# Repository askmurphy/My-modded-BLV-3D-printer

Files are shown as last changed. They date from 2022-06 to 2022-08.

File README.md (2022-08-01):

# My modded BLV 3D-printer

For starters I build the original BLV printer following the original design.
It worked but because I build the largest version, it didn't print very good..
So, time to do some modifications, a lot of them....  Finally I am now at my BLV printer version 3 ;-)

# <strong>My current setup:</strong> 

# HARDWARE:
* BLV Alu profiles
* Original Duet2Wifi board
* Clone Duex5 board
* Big heated bed
* Orbiter 1.5 extruder
* NF Crazy hotend
* Triple Z-as (SFU1204, MGN rails)
* Accelerator
* 24V Meanwell PSU

| Just a few photo's | Click to enlarge..|
|---|---|

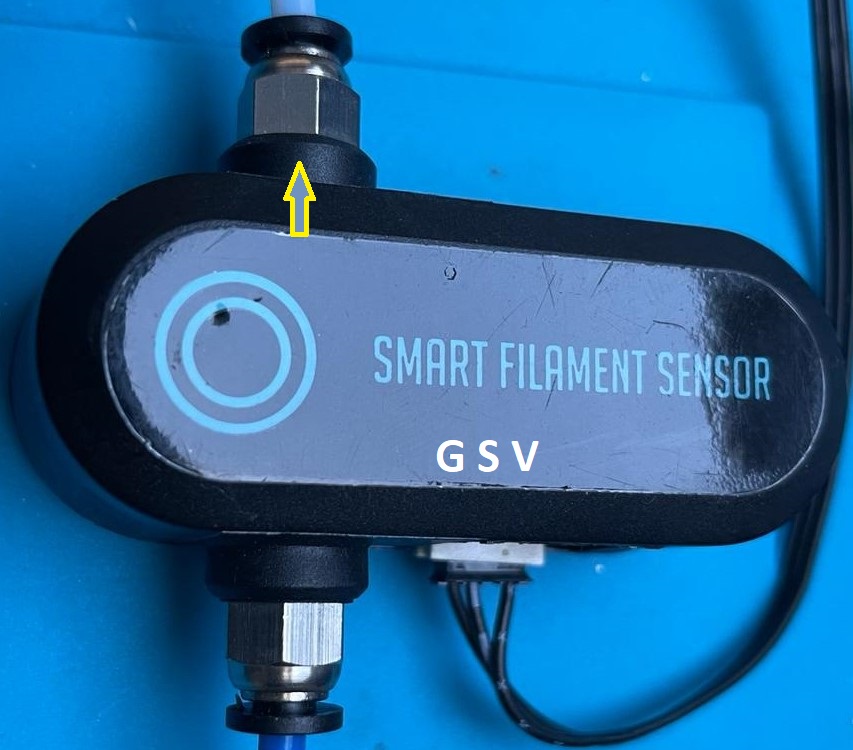
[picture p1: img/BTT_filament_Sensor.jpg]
BTT smart filament sensor Bigtreetech filament sensor
|  

# FIRMWARE:
* RepRapFirmware for Duet 2 WiFi/Ethernet 3.4.0 (2022-03-15)
* Duet WiFi Server Version: 1.26
* Duet Web Control 3.4.0

# Accelerator LIS3DSH
Because this device needs a very good shielded cable to avoid malfunctions, I have used an UTP CAT7 cable. The accelerator can be connected to the 10 pins header named 'TEMP DAUGHTERBOARD', located on the DUET2WIFI and DUEX5, wiring:

| UTP | Accelerator | DUET2WIFI | DUEX5 |
|---|---|---|---|
| UTP[1] white/orange | INT1 | SPI_CS3[7]  | SPI_CS7[7]  | 
| UTP[2] orange | GND | GND[2] | GND[2] | 
| UTP[3] white/green  | VCC | 3.3V[8] | 3.3V[8] |
| UTP[4] blue | SCL | SPI_SCK[4]  | SPI_SCK[4]  | 
| UTP[5] blue/white | SDA | SPI_MOSI[5] | SPI_MOSI[5] |
| UTP[6] green | 1KOhm <-> SDO/SAO | SPI_MISO[6] | SPI_MISO[6] |
| UTP[7] brown/white  | Not connected | | |
| UTP[8] brown | CS | SPI_CS4[9]  | SPI_CS8[9]  |

* Note1: a 1K resistor must be fitted between SDO/SAO and UTP[6]
* Note2: just use one connector, DUET2WIFI or DUEX5
 
# CONFIGURATION:

* Everything located in /config/ folder..

 >>>> All configurations and Macros are UNDER CONSTRUCTION, don't use them !!! <<<<

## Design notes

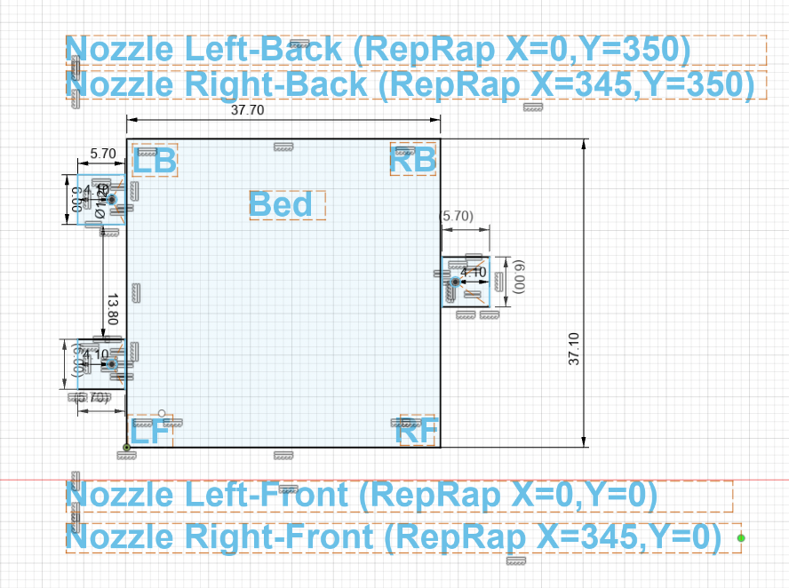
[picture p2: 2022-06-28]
img/Topview dimensions bed.png

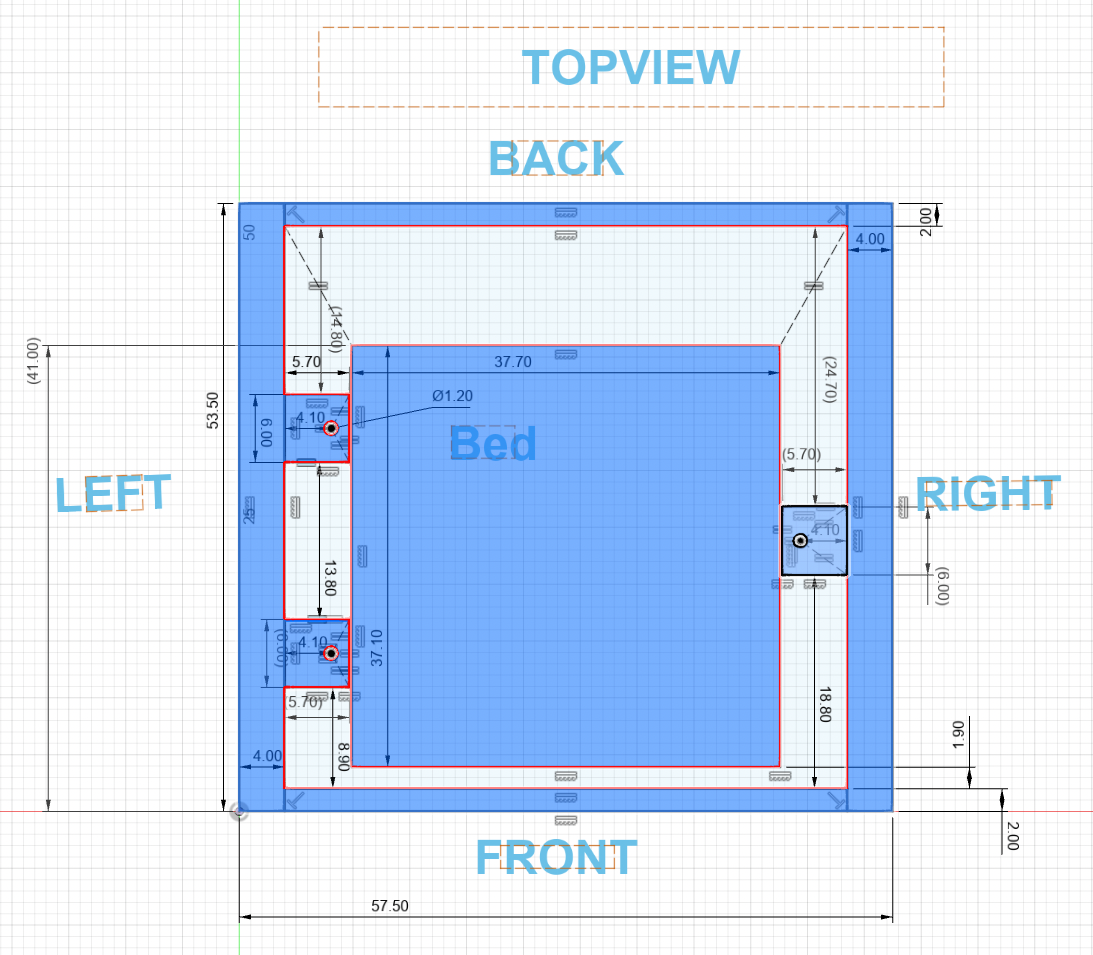
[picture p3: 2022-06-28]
img/Topview dimensions BLV bed.png

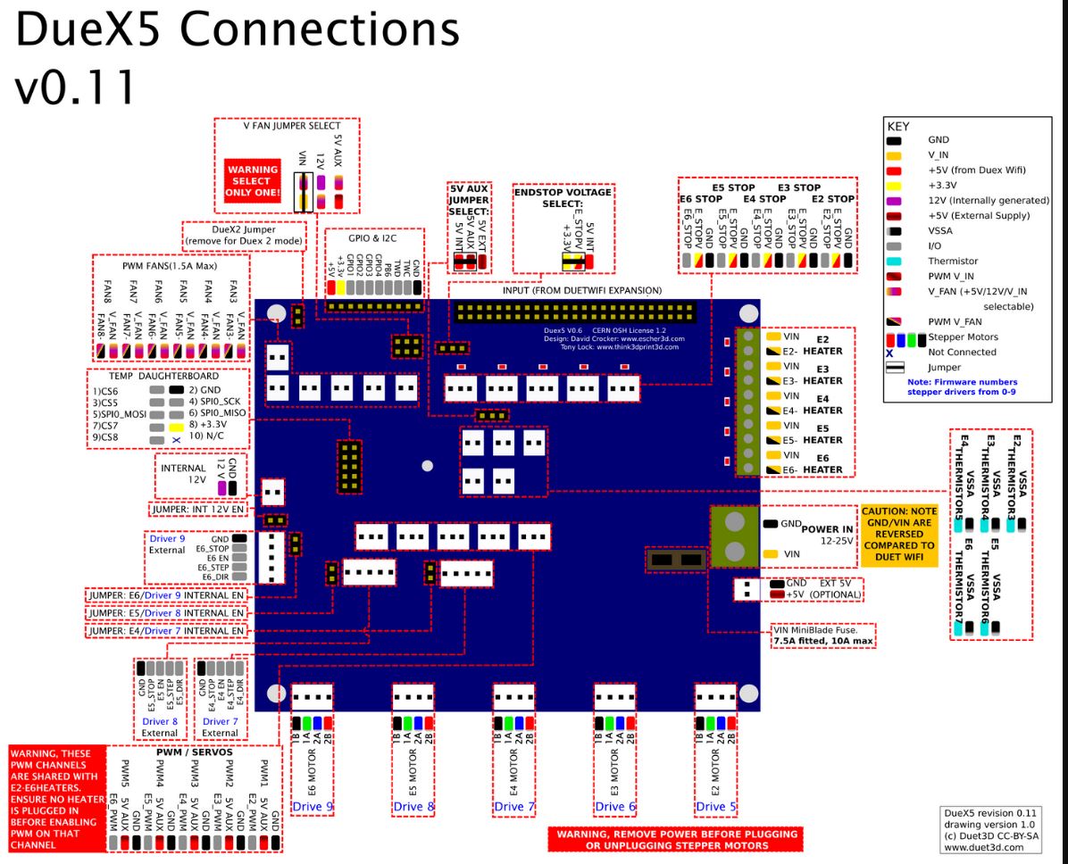
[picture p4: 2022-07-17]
img/duex5.JPG

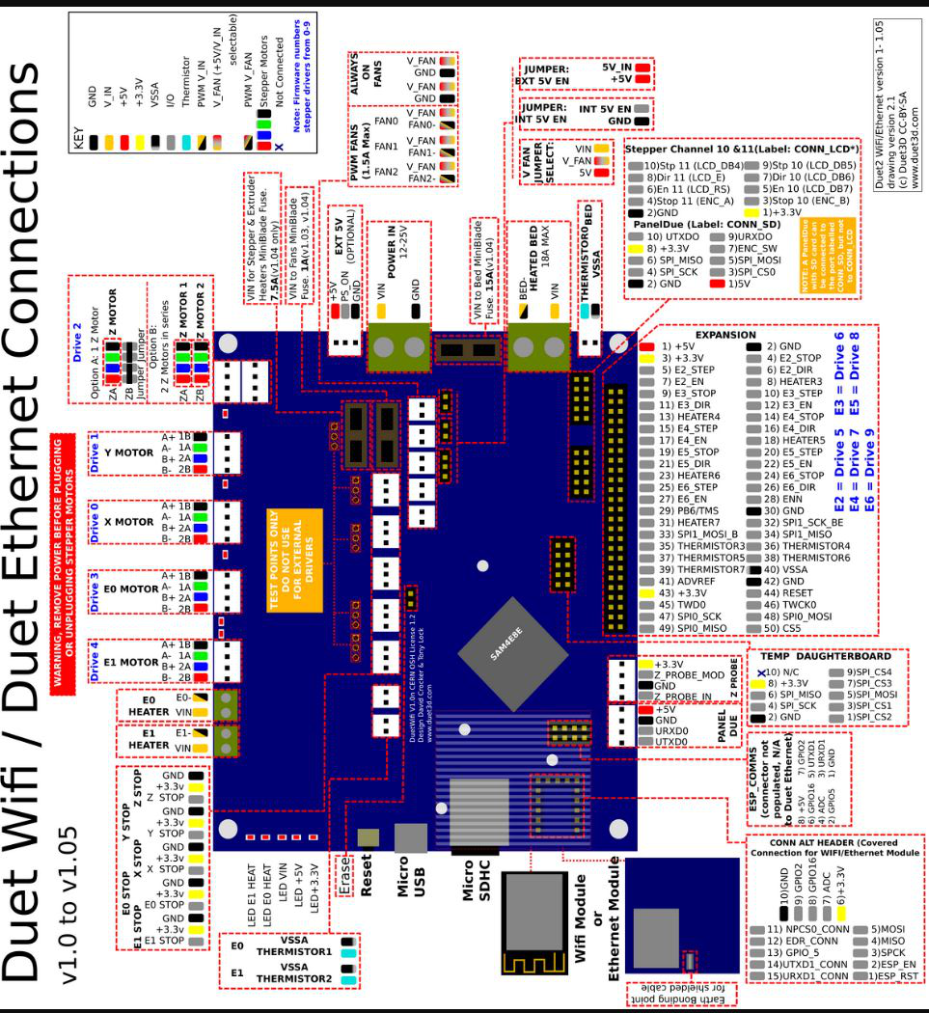
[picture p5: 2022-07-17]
img/duet2wifi.JPG

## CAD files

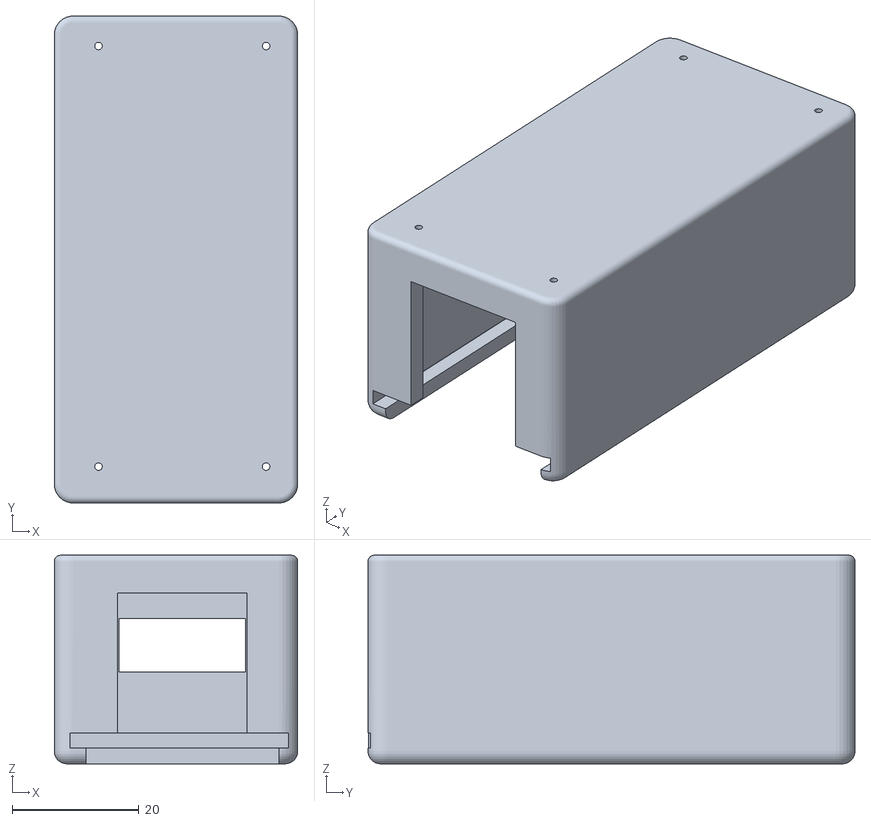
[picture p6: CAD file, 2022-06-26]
stl/accelerometer/accelerator-UTP.stl
38.5 x 77.0 x 33.0

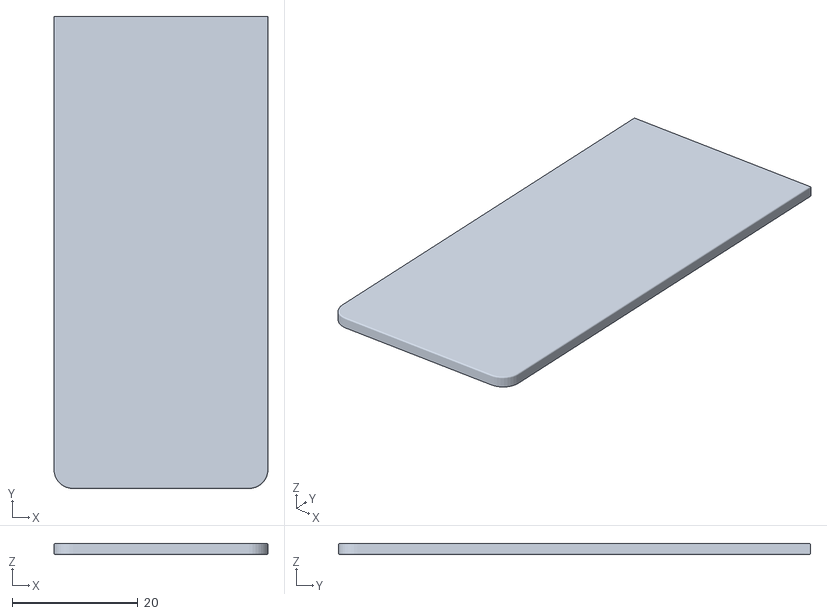
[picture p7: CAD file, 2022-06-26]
stl/accelerometer/accelerator-UTP-LID.stl
34.0 x 75.0 x 1.80

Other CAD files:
stl/accelerometer/Accelerator UTP v8.f3d

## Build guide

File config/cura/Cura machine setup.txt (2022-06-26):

Printer settings:
X: 345mm
Y: 350mm
Z: 630mm

Heated Rectangular bed

G-code flavor: RepRap

Printerhead Settings:
X min: -20mm
Y min: -10mm
X max: 10mm
Y max: 10mm
Gantry Height: 0.0mm
Number of extruders: 1
Apply Extruder to GCode: enabled

Extruder:
0.4mm nozzle
Filament 1.75mm
Nozzle offset X: 0mm
Nozzle offset Y: 0mm
Cooling Fan Number: 0

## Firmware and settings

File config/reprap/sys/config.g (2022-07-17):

; Configuration file for Duet WiFi (firmware version 3)
; executed by the firmware on start-up
;
; generated by RepRapFirmware Configuration Tool v3.2.3 on Tue Jun 08 2021 11:55:25 GMT+0200 (Midden-Europese zomertijd)

; https://duet3d.dozuki.com/Wiki/Test_and_calibrate_the_Z_probe
; To apply the new trigger height, restart the Duet by sending M999 or pressing Emergency Stop.


; General Global Preferences and critical Drive Configuration Section -  These must come before all else.
M80																; ATX ON
G4 P2000														; Hold your Horses.  Add a little time to allow things to settle and complete.
G90  															; send absolute coordinates...
M83  															; ...but relative extruder moves
G21																; Set units to Millimeters
M550 P"Arthur's BLV mgn Cube" 									; set printer name -  change this to whatever you'd like
;M584 X0 Y1 Z7:8:9 E3 										; set drive mapping to each axis 
																;  Note the M567 commage later.  These are related and connected.  This command must always come
																; before a number of other commands.  Refer to https://duet3d.dozuki.com/Wiki/RepRapFirmware_3_overview
M669 K1															; Select CoreXY mode - New format
; ---------------------------------------------------------------------------------------------------------------------------------------------------------------------------------------
;
; Network Configuration Section
M552 S1 														; enable network
;M587 S"...."							; Add a WiFi host network to the rememebred list. Once you connected properly, you can delete this line.
M586 P0 S1                                                ; enable HTTP
M586 P1 S1                                                ; disable FTP
M586 P2 S0                                                ; disable Telnet

; ---------------------------------------------------------------------------------------------------------------------------------------------------------------------------------------
;
; Drives - Establish the Drive designation and the direction they turn.
; Validate these settings as a first step.
; If your wiring differs, you can fix the direction here instead of rewiring.
M569 P0 S1														; physical drive 0 goes forwards
M569 P1 S1 														; physical drive 1 goes forwards
M569 P2 S0 														; placeholder for unused drive.
M569 P3 S1 														; physical drive 3 goes forward: extruder
M569 P4 S1 														; placeholder for unused drive. Erratic behavior can occur if unused drivers are not bound to a driver.
M569 P5 S0														; placeholder for unused drive.
M569 P6 S0														; placeholder for unused drive.
M569 P7 S1														; physical drive 7 goes forward - z-axis: right middle
M569 P8 S1														; physical drive 8 goes forward - z-axis: left front
M569 P9 S1														; physical drive 9 goes forward - z-axis: left back

M584 X0 Y1 Z8:9:7 E3; three Z motors connected to driver outputs 8 (left front), 9 (left back) and 7 (right middle)
M671 X-29:-29:386 Y36.5:233:136.5 S10 ; leadscrews at left front, left back and right middle
																; This tells the Duet the physical location of the center of the leadscrews.
																; for reference the order/sequence of defined coordinate positions MUST correspond to
																; the order of axis drives that was specified above in the M584 gcode 

M92 X200.00 Y200.00 Z800.00 E411.41 							; set steps per mm, based on using 0.9 degree steppers for X/Y and 1.8 degree steppers for the Z axis.

M350 X16 Y16 Z16 E16 I1 										; configure micro-stepping with interpolation
M566 X600.00 Y600.00 Z24.00 E300.00 							; set maximum instantaneous speed changes (mm/min)
M203 X15000.00 Y15000.00 Z600.00 E2000.00 						; set maximum speeds (mm/min) *EDP*
M201 X4000.00 Y4000.00 Z100.00 E5000.00 						; set accelerations (mm/s^2)
M204 P2000 T4000												; set printing and travel acceleration

;M906 X800 Y800 Z800 E800 I30 									; set motor currents (mA) and motor idle factor in per cent
;M906 X800 Y800 Z800 E400 I30 									; set motor currents (mA) and motor idle factor in per cent
M906 X800 Y800 Z800 E800 I30 									; set motor currents (mA) and motor idle factor in per cent


M84 S30  														; Set idle timeout

M572 D0 S0.05 ; https://duet3d.dozuki.com/Wiki/Pressure_advance
;M593 ringing reduction
;
; ---------------------------------------------------------------------------------------------------------------------------------------------------------------------------------------
; Axis Limits
M208 X0 Y0 Z0 S1                                          ; set axis minima
M208 X345 Y350 Z630 S0                                    ; set axis maxima
; ---------------------------------------------------------------------------------------------------------------------------------------------------------------------------------------
; Endstops
M574 X1 S1 P"xstop"                                       ; configure active-high endstop for low end on X via pin xstop
M574 Y2 S1 P"ystop"                                       ; configure active-high endstop for high end on Y via pin ystop
M574 Z1 S2                                                ; configure Z-probe endstop for low end on Z
; ---------------------------------------------------------------------------------------------------------------------------------------------------------------------------------------
; filament sensor
M574 E2 S1 P"e0stop" ; configure active-high endstop for high end on E via pin estop
;M591 D0 P7 C"e0stop" L7 R1:900 E15 S1 ;configure BTT smart filament sensor
; ---------------------------------------------------------------------------------------------------------------------------------------------------------------------------------------
; Z-Probe
M950 S0 C"duex.pwm5"                                      ; create servo pin 0 for BLTouch
;orgM558 P9 C"^zprobe.in" H5 F120 T6000                       ; set Z probe type to bltouch and the dive height + speeds
M558 P9 C"^zprobe.in" H10 F300 T9000                       ; set Z probe type to bltouch and the dive height + speeds

;G31 P500 X-0.1 Y58 Z1.114                                  ; (24-6-2022) set Z probe trigger value, offset and trigger height, te ver van het bed, Z offset iets groter
;G31 P500 X-0.1 Y58 Z1.185 ; t1
;G31 P500 X-0.1 Y58 Z1.195 ; t2 iets beter 
;G31 P500 X-0.1 Y58 Z1.205 ; t3 zelfde niet goed
;G31 P500 X-0.1 Y58 Z0.80 ; 
;G31 P500 X-0.1 Y58 Z1.089 ; macro 
;G31 P500 X-0.1 Y58 Z0.989 ; finetuning babysteps te ver
G31 P500 X-0.1 Y58 Z1.077 ; 
; ------------------------------------------------------------------------------------------------------------------------
;
; Configure Heaters and Sensors
;
M308 S0 P"bedtemp" Y"thermistor" T100000 B4138            ; configure sensor 0 as thermistor on pin bedtemp
M950 H0 C"bedheat" T0                                     ; create bed heater output on bedheat and map it to sensor 0
M307 H0 B1 S1.00                                          ; enable bang-bang mode for the bed heater and set PWM limit
M140 H0                                                   ; map heated bed to heater 0
M143 H0 S90                                              ; set temperature limit for heater 0 to 90C
M308 S1 P"e0temp" Y"thermistor" T500000 B4723 C1.19622e-7 ; configure sensor 1 as thermistor on pin e0temp
M950 H1 C"e0heat" T1                                      ; create nozzle heater output on e0heat and map it to sensor 1
M307 H1 B0 S1.00                                          ; disable bang-bang mode for heater  and set PWM limit
M143 H1 S260                                              ; set temperature limit for heater 1 to 260C

; ---------------------------------------------------------------------------------------------------------------------------------------------------------------------------------------
;
; Fans
M950 F0 C"fan0" Q500                                      ; create fan 0 on pin fan0 and set its frequency
M106 P0 C"Layer Fan" S0 H-1                               ; set fan 0 value. Thermostatic control is turned off
M950 F1 C"fan1" Q500                                      ; create fan 1 on pin fan1 and set its frequency
M106 P1 C"HOTEND-FAN" T45 S1 H1                       ; set fan 1 name and value. Thermostatic control is turned on : S1
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

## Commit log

2022-06-26 reprap configuration
    [-0.000mm Less Reprime (OFF).g, -0.025mm Less Reprime.g, -0.050mm Less Reprime.g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]
2022-06-26 Accelerator UTP-adapter
    [Accelerator UTP v8.f3d, accelerator-UTP-LID.stl, accelerator-UTP.stl]
2022-06-28 Create Topview dimensions BLV bed.png
2022-06-28 Create Topview dimensions bed.png
2022-07-04 Sys en macro's updated
    [0_2022-06-08_16.33.07.csv, 0_2022-06-08_16.33.26.csv, 0_2022-06-11_19.57.41.csv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]
